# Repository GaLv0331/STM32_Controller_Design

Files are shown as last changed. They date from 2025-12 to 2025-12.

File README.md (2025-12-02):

# ⚡️ STM32F405RGT6 Controller Design

3D Render of the Custom PCB




***

## 🌟 Overview

This repository contains the complete **hardware design files** for a custom controller board built around the powerful **STM32F405RGT6** microcontroller.

The design is engineered for high-performance control applications and features integrated **RF wireless communication** capabilities, making it suitable for projects such as remote control systems, robotics, or advanced data acquisition platforms.

All schematics and PCB layout files were created using the **KiCad** open-source EDA suite.

***

## 🎯 Key Features and Components

| Feature | Description | Related Files |
| :--- | :--- | :--- |
| **Microcontroller** | **STM32F405RGT6** (Cortex-M4, 168 MHz) is the core processing unit. | `STM32.kicad_sch`, `STM32.kicad_pcb` |
| **Wireless Interface** | Dedicated circuitry for an **nRF** series radio module (e.g., nRF24L01). | `nrf.kicad_sch` |
| **Design Platform**| Complete PCB layout and schematic captured in KiCad. | `STM32.kicad_pro`, `STM32.kicad_pcb` |
| **Connectivity** | Includes necessary debugging headers (SWD/JTAG), power supply, and breakout points for peripherals. | |

***

## 📂 Design Files Structure

The project is managed entirely within **KiCad**. The following files are included in the main directory:

| File Name | Description |
| :--- | :--- |
| `STM32.kicad_pro` | The main KiCad project file. |
| `STM32.kicad_sch` | The primary schematic document for the STM32 controller. |
| `STM32.kicad_pcb` | The complete PCB layout file, including routing, layers, and footprints. |
| `nrf.kicad_sch` | A separate schematic sheet detailing the integration of the nRF wireless module. |
| `RF(pin change).kicad_sym` | Custom schematic symbol for the RF component or a related section. |

***

## 🛠️ Getting Started (Viewing the Design)

To open, inspect, or modify the design files, you must have KiCad installed.

### Prerequisites

1.  **KiCad EDA:** Download and install the latest stable version from the [official KiCad website](https://www.kicad.org/download/).

### How to Open

1.  **Clone the Repository:**
    ```bash
    git clone [https://github.com/GaLv0331/STM32F405RGT6_Controller_Design.git](https://github.com/GaLv0331/STM32F405RGT6_Controller_Design.git)
    ```
2.  **Open Project:** Launch KiCad and open the main project file: `STM32.kicad_pro`.
3.  From the KiCad project manager, you can then launch the Schematic Editor or the PCB Layout Editor to view the respective files.

***

## 📄 License

This project is open-source and released under the **MIT License**. See the `LICENSE` file for more details.

***

## 📞 Contact

For questions, bug reports, or contributions, please feel free to open a GitHub Issue in this repository.

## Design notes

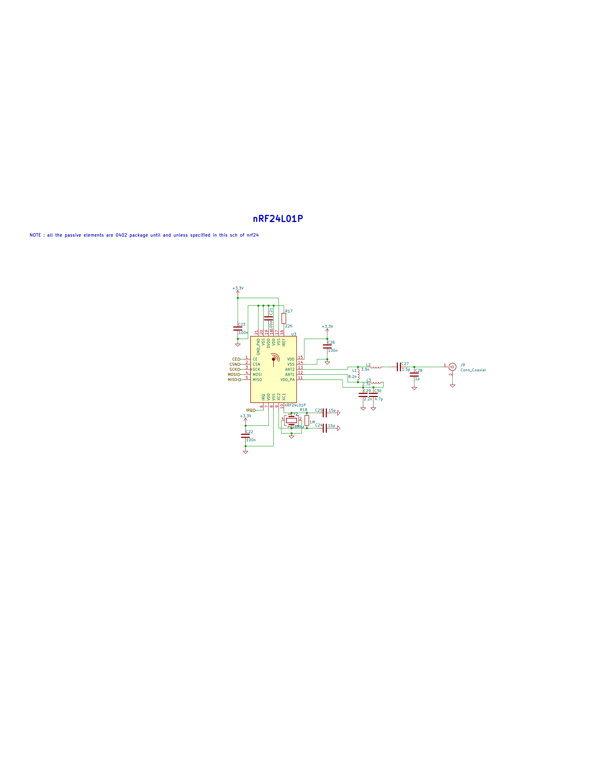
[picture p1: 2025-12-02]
assets/nrf.png

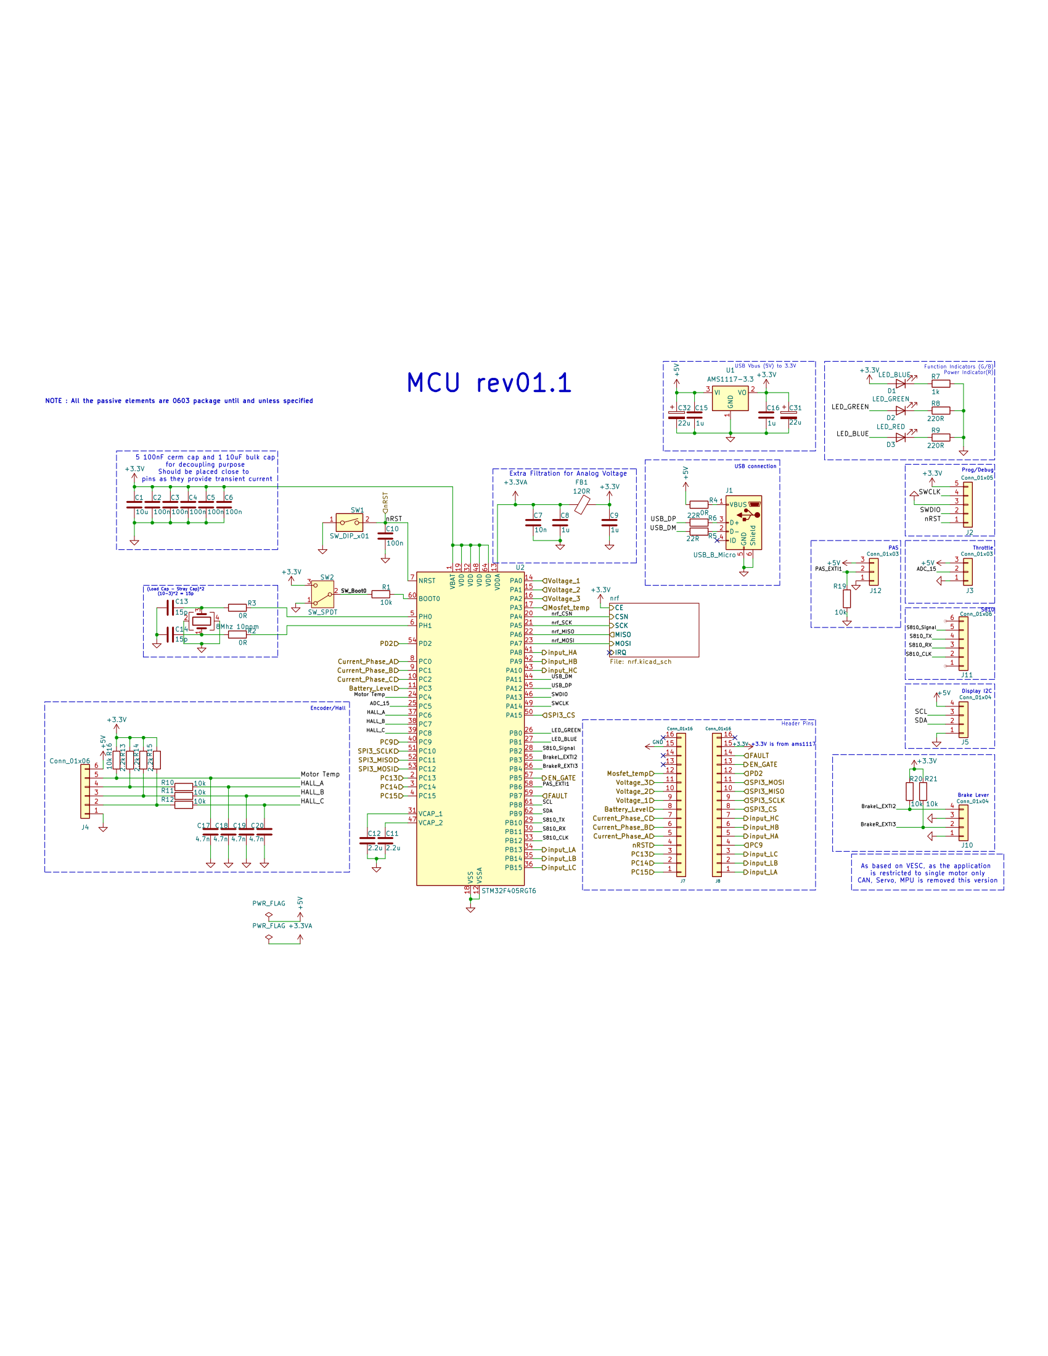
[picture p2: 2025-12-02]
assets/stm32f405rgt6.png

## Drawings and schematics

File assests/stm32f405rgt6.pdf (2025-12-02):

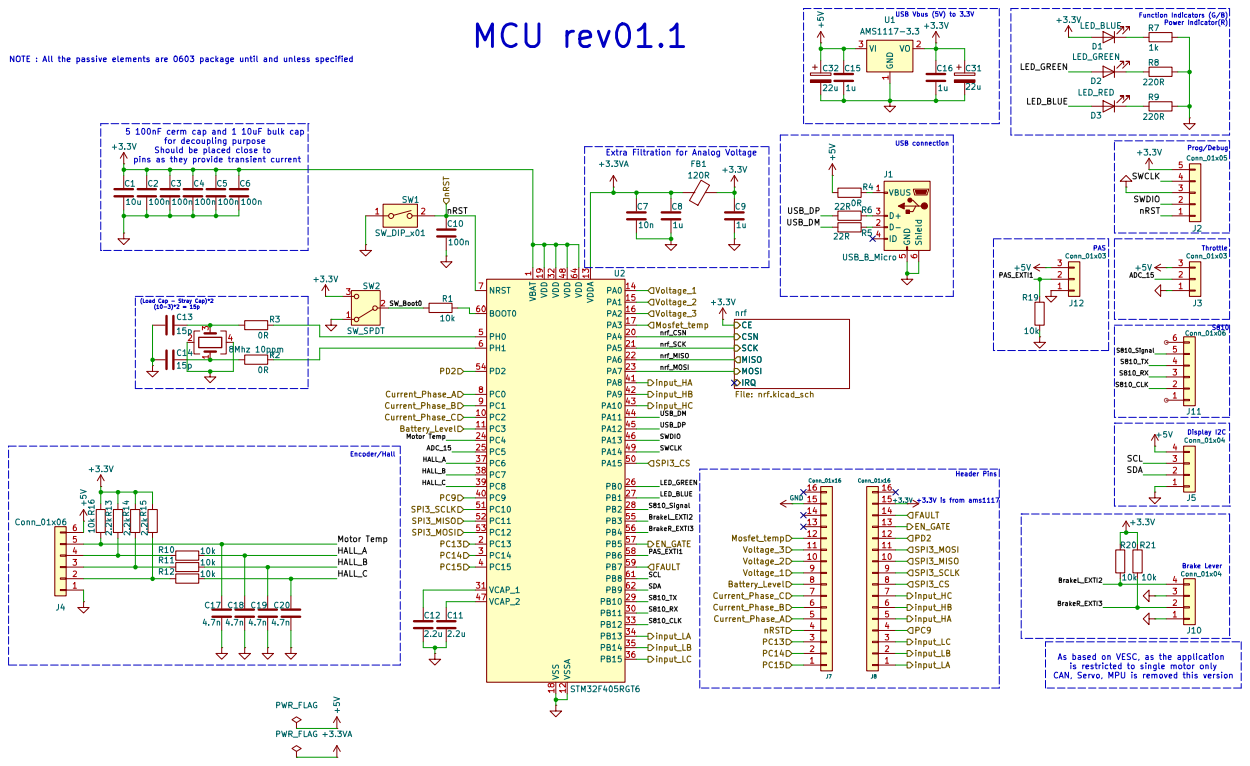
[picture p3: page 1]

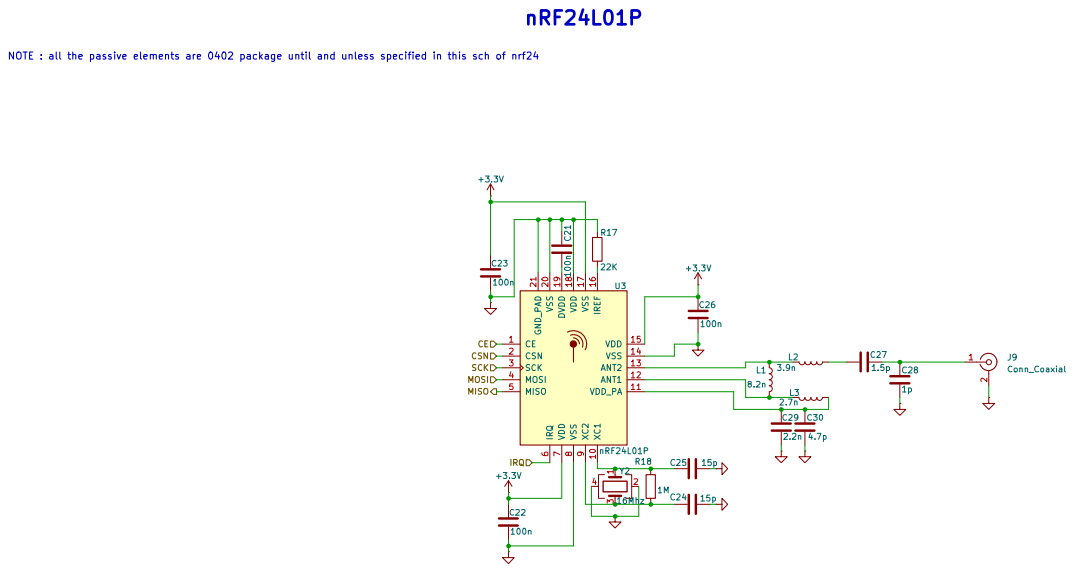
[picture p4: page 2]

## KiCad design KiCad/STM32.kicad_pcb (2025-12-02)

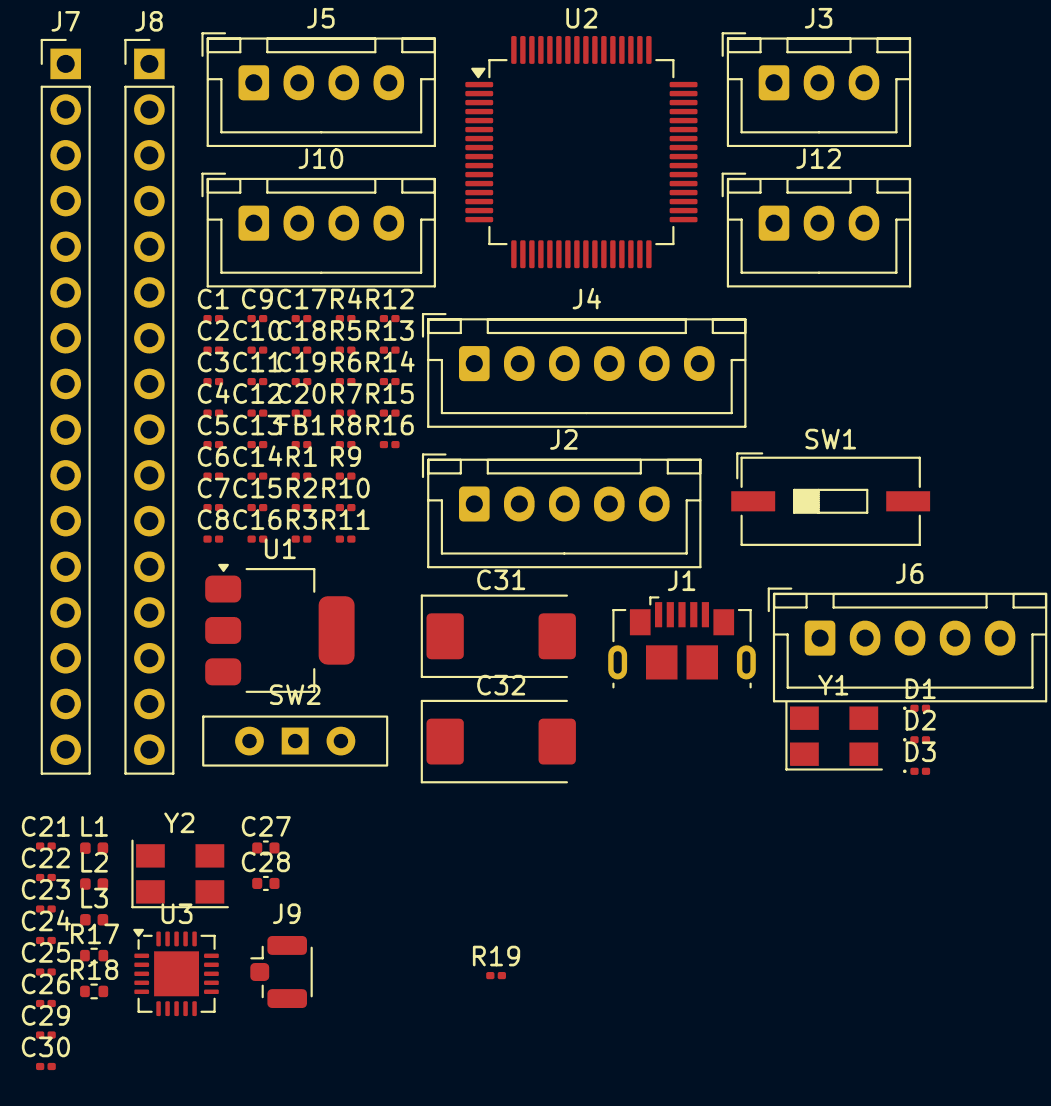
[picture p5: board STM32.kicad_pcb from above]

Board: 2 copper layers, 76 parts (0 on the bottom side), 80 nets, no tracks yet.

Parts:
C1: 10u; C_0201_0603Metric
C2, C3, C4, C5, C6, C10, C21, C22, C23, C26: 100n; C_0201_0603Metric
C7: 10n; C_0201_0603Metric
C8, C9, C15, C16: 1u; C_0201_0603Metric
C11, C12: 2.2u; C_0201_0603Metric
C13, C14, C24, C25: 15p; C_0201_0603Metric
C17, C18, C19, C20: 4.7n; C_0201_0603Metric
C27: 1.5p; C_0402_1005Metric
C28: 1p; C_0402_1005Metric
C29: 2.2n; C_0201_0603Metric
C30: 4.7p; C_0201_0603Metric
C31, C32: 22u; CP_EIA-7343-31_Kemet-D
D1: LED_RED; LED_0201_0603Metric
D2: LED_GREEN; LED_0201_0603Metric
D3: LED_BLUE; LED_0201_0603Metric
FB1: 120R; L_0201_0603Metric
J1: USB_B_Micro; USB_Micro-B_GCT_USB3076-30-A
J2, J6: Conn_01x05; JST_XH_B5B-XH-A_1x05_P2.50mm_Vertical
J3, J12: Conn_01x03; JST_XH_B3B-XH-A_1x03_P2.50mm_Vertical
J4: Conn_01x06; JST_XH_B6B-XH-A_1x06_P2.50mm_Vertical
J5, J10: Conn_01x04; JST_XH_B4B-XH-A_1x04_P2.50mm_Vertical
J7, J8: Conn_01x16; PinHeader_1x16_P2.54mm_Vertical
J9: Conn_Coaxial; U.FL_Hirose_U.FL-R-SMT-1_Vertical
L1: 8.2n; L_0402_1005Metric
L2: 3.9n; L_0402_1005Metric
L3: 2.7n; L_0402_1005Metric
R1, R10, R11, R12, R16, R19: 10k; R_0201_0603Metric
R2, R3, R4: 0R; R_0201_0603Metric
R5, R6: 22R; R_0201_0603Metric
R7: 1k; R_0201_0603Metric
R8, R9: 220R; R_0201_0603Metric
R13, R14, R15: 2.2k; R_0201_0603Metric
R17: 22K; R_0402_1005Metric
R18: 1M; R_0402_1005Metric
SW1: SW_DIP_x01; SW_DIP_SPSTx01_Slide_9.78x4.72mm_W8.61mm_P2.54mm
SW2: SW_SPDT; SW_Slide-03_Wuerth-WS-SLTV_10x2.5x6.4_P2.54mm
U1: AMS1117-3.3; SOT-223-3_TabPin2
U2: STM32F405RGT6; LQFP-64_10x10mm_P0.5mm
U3: nRF24L01P; QFN-20-1EP_4x4mm_P0.5mm_EP2.5x2.5mm
Y1: 8Mhz 10ppm; Crystal_SMD_5032-4Pin_5.0x3.2mm
Y2: 16Mhz; Crystal_SMD_5032-4Pin_5.0x3.2mm

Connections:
+3.3V: C1.1, C2.1, C3.1, C4.1, C5.1, C6.1, C9.1, C16.1, C22.1, C23.1, C26.1, C31.1, D1.2 (A), FB1.2, J2.5, J8.15, R13.1, R14.1, R15.1, R16.2, SW2.3 (C), U1.2 (VO), U2.1 (VBAT), U2.19 (VDD), U2.32 (VDD), U2.48 (VDD), U2.64 (VDD), U3.1 (CE), U3.7 (VDD), U3.15 (VDD), U3.17 (VSS)
+3.3VA: C7.1, C8.1, FB1.1, U2.13 (VDDA)
+5V: C15.1, C32.1, J3.3, J4.6, J5.4, J6.5, J8.16, J12.3, R4.1, U1.3 (VI)
/ADC_15: J3.2, U2.25 (PC5)
/Battery_Level: J7.8, U2.11 (PC3)
/BrakeL_EXTI2: J10.4, U2.55 (PB3)
/BrakeR_EXTI3: J10.2, U2.56 (PB4)
/Current_Phase_A: J7.5, U2.8 (PC0)
/Current_Phase_B: J7.6, U2.9 (PC1)
/Current_Phase_C: J7.7, U2.10 (PC2)
/EN_GATE: J8.13, U2.57 (PB5)
/FAULT: J8.14, U2.59 (PB7)
/HALL_A: C18.1, R10.2, U2.37 (PC6)
/HALL_B: C19.1, R11.2, U2.38 (PC7)
/HALL_C: C20.1, R12.2, U2.39 (PC8)
/LED_BLUE: D3.2 (A), U2.27 (PB1)
/LED_GREEN: D2.2 (A), U2.26 (PB0)
/Mosfet_temp: J7.12, U2.17 (PA3)
/Motor Temp: C17.1, J4.5, R16.1, U2.24 (PC4)
/PAS_EXTI1: J12.2, R19.2, U2.58 (PB6)
/PB2: J7.13, U2.28 (PB2)
/PC9: J8.4, U2.40 (PC9)
/PC13: J7.3, U2.2 (PC13)
/PC14: J7.2, U2.3 (PC14)
/PC15: J7.1, U2.4 (PC15)
/PD2: J8.12, U2.54 (PD2)
/S810_CLK: J6.2, U2.33 (PB12)
/S810_RX: J6.3, U2.30 (PB11)
/S810_TX: J6.4, U2.29 (PB10)
/SCL: J5.3, U2.61 (PB8)
/SDA: J5.2, U2.62 (PB9)
/SPI3_CS: J8.8, U2.50 (PA15)
/SPI3_MISO: J8.10, U2.52 (PC11)
/SPI3_MOSI: J8.11, U2.53 (PC12)
/SPI3_SCLK: J8.9, U2.51 (PC10)
/SWCLK: J2.4, U2.49 (PA14)
/SWDIO: J2.2, U2.46 (PA13)
/SW_Boot0: R1.1, SW2.2 (B)
/USB_DM: R5.1, U2.44 (PA11)
/USB_DP: R6.1, U2.45 (PA12)
/Voltage_1: J7.9, U2.14 (PA0)
/Voltage_2: J7.10, U2.15 (PA1)
/Voltage_3: J7.11, U2.16 (PA2)
/input_HA: J8.5, U2.41 (PA8)
/input_HB: J8.6, U2.42 (PA9)
/input_HC: J8.7, U2.43 (PA10)
/input_LA: J8.1, U2.34 (PB13)
/input_LB: J8.2, U2.35 (PB14)
/input_LC: J8.3, U2.36 (PB15)
/nRST: C10.1, J2.1, J7.4, SW1.2, U2.7 (NRST)
/nrf_CSN: U2.20 (PA4), U3.2 (CSN)
/nrf_MISO: U2.22 (PA6), U3.5 (MISO)
/nrf_MOSI: U2.23 (PA7), U3.4 (MOSI)
/nrf_SCK: U2.21 (PA5), U3.3 (SCK)
GND: C1.2, C2.2, C3.2, C4.2, C5.2, C6.2, C7.2, C8.2, C9.2, C10.2, C11.2, C12.2, C13.2, C14.2, C15.2, C16.2, C17.2, C18.2, C19.2, C20.2, C21.1, C22.2, C23.2, C24.2, C25.2, C26.2, C28.2, C29.2, C30.2, C31.2, C32.2, J1.5 (GND), J1.6 (Shield), J2.3, J3.1, J4.1, J5.1, J6.1, J7.15, J7.16, J9.2 (Ext), J10.1, J10.3, J12.1, R7.1, R8.1, R9.1, R17.1, R19.1, SW1.1, SW2.1 (A), U1.1 (GND), U2.12 (VSSA), U2.18 (VSS), U2.63 (VSS), U3.8 (VSS), U3.14 (VSS), U3.18 (VDD), U3.20 (VSS), U3.21 (GND_PAD), Y1.2, Y1.4, Y2.2, Y2.4
unnamed: C13.1, R3.1, Y1.3
unnamed: C14.1, R2.1, Y1.1
unnamed: C27.1, L2.1
unnamed: D1.1 (K), R7.2
unnamed: D2.1 (K), R8.2
unnamed: D3.1 (K), R9.2
unnamed: J1.3 (D+), R6.2
unnamed: J1.2 (D-), R5.2
unnamed: J1.1 (VBUS), R4.2
unnamed: J4.2, R12.1, R15.2
unnamed: J4.3, R11.1, R14.2
unnamed: J4.4, R10.1, R13.2
unnamed: C27.2, C28.1, J9.1 (In)
unnamed: R1.2, U2.60 (BOOT0)
unnamed: R3.2, U2.5 (PH0)
unnamed: R2.2, U2.6 (PH1)
unnamed: C12.1, U2.31 (VCAP_1)
unnamed: C11.1, U2.47 (VCAP_2)
unnamed: L1.2, L3.2, U3.12 (ANT1)
unnamed: L1.1, L2.2, U3.13 (ANT2)
unnamed: C21.2, U3.19 (DVDD)
unnamed: R17.2, U3.16 (IREF)
unnamed: C29.1, C30.1, L3.1, U3.11 (VDD_PA)
unnamed: C25.1, R18.1, U3.10 (XC1), Y2.1
unnamed: C24.1, R18.2, U3.9 (XC2), Y2.3

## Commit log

2025-12-02 Create KiCad_Files
2025-12-02 Update and rename RF(pin change).kicad_sym to KiCad/RF(pin change).kicad_sym
2025-12-02 Update and rename STM32.kicad_pcb to KiCad/STM32.kicad_pcb
    [STM32.kicad_pcb]

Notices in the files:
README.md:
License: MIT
